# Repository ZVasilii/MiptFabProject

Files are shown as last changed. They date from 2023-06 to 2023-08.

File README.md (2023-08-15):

# Робот-бармен

Идея проекта в создании робота-бармена для использования его на студенческих мероприятиях. 
Проект был создан на "Физтех.Фабрике" в 2023 году.

### Авторы

Студенты 4 Курса ФРКТ:

Зайцев Василий  
Алексей Быков  
Касков Михаил  

## Подробнее

См. презентацию [здесь](https://github.com/ZVasilii/MiptFabProject/blob/master/%D0%A0%D0%BE%D0%B1%D0%BE%D1%82-%D0%B1%D0%B0%D1%80%D0%BC%D0%B5%D0%BD.pptx)

### Собранное устройство



## Используемые компоненты

* Arduino Nano
* Энкодер с кнопкой
* Аквариумный насос
* Пищевой силиконовый шланг
* Шаговый двигатель 28BYJ-48 5V
* Сервопривод FS5103B
* Тензодатчик (датчик веса)
* Экран Lcd 1602 I2C

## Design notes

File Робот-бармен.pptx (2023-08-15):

## Робот-бармен

Выполнили студенты ФРКТ
Зайцев Василий Б01-909
Быков Алексей Б01-908
Касков Михаил Б01-909

## Цель

- Избавить студентов от необходимости замешивать напитки самостоятельно
- Обеспечить честность и непредвзятость при наливании
- Разработать недорогое, практичное и масштабируемое решение

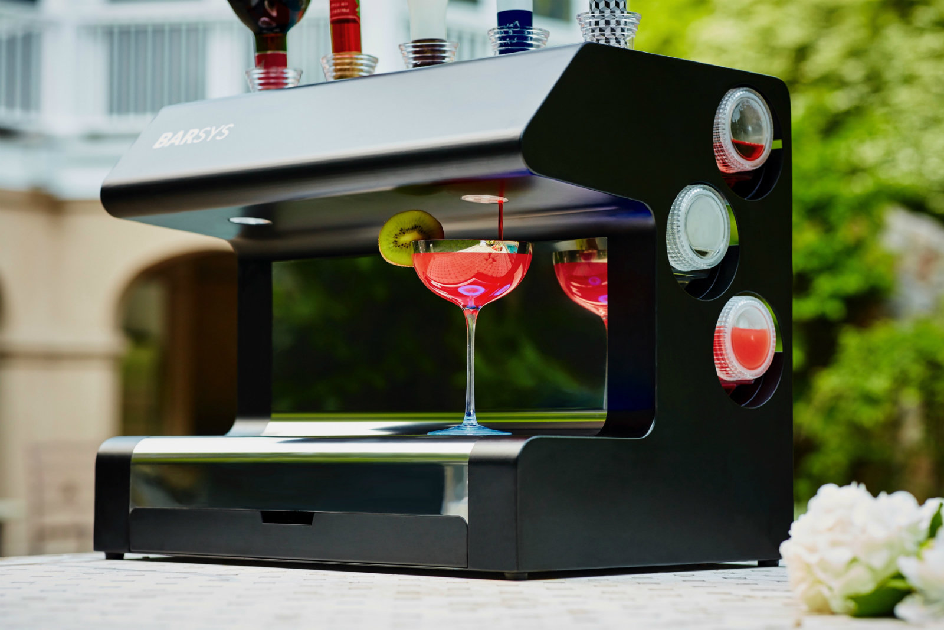
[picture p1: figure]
Робот-бармен» Barsys стоимостью 1500 долларов наделен искусственным интеллектом

## Схема Работы

Выбор напитка через энкодер, индикация на LCD

Выбор нужной емкости, включение насоса

Контроль веса тензодатчиком, остановка насоса

Окончание приготовления, индикация светодиодом

## Первый прототип клапана выбора

- Основан на циллиндре с отверстиями
- Выбор осуществлялся поворотом шагового двигателя
- Недостаток – низкая герметичность не позволяла обеспечить нужное давление

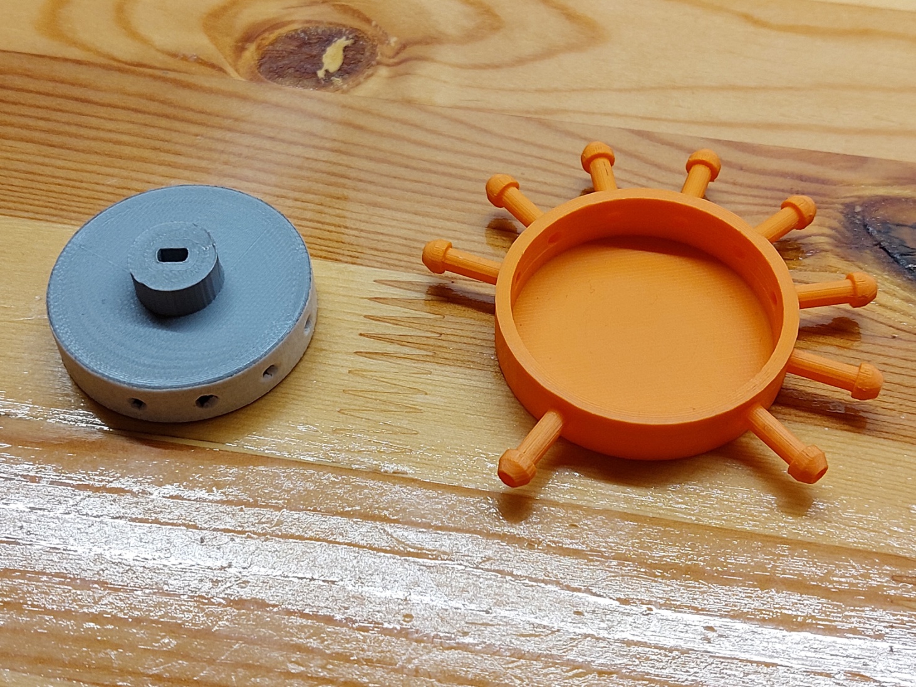
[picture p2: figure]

## Рабочее решение клапана выбора

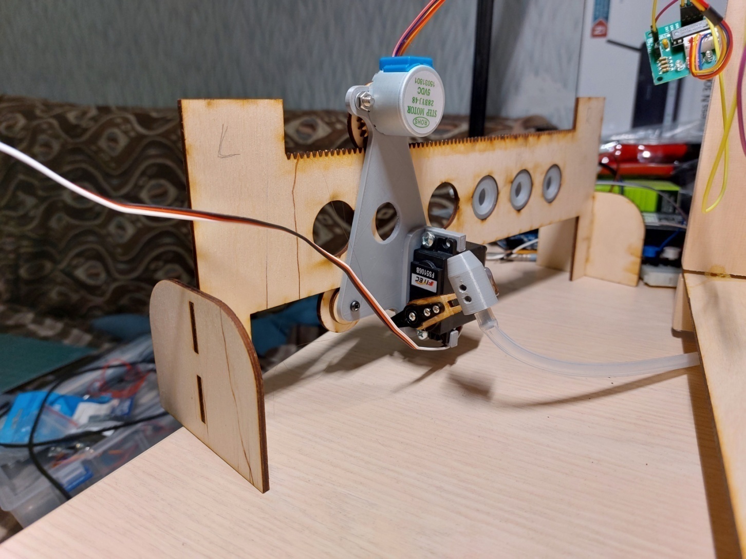
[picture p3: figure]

- Основан на рельсе с отверстиями
- Выбор происходит шаговым двигателем
- «Стыковка» и герметизация - серводвигателем

## API для добавления рецептов

- changeValve – сменить емкость
- pumpON/OFF – вкл/выкл насос
- waitForGramms – к-во грамм, сколько нужно налить

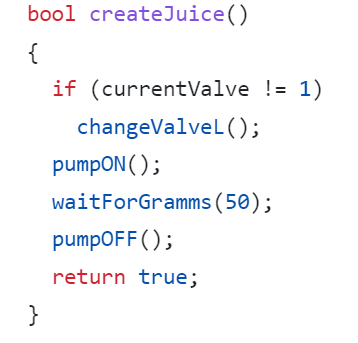
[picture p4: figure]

## Достоинства и недостатки нашего решения

- Достоинства:
  - Простота и дешевизна конструкции (около 1000р)
  - Открытый исходный код и доступные материалы
  - Система построена так, что «живительный напиток» проходит только через трубки из пищевого силикона и не соприкасается с клапанами/насосами
  - Масштабируемость, удобный API для введения новых рецептов
  - Удобный user interface, индикация работы
  - Недостатки
    - Стабильность работы клапана выбора

## Использованные компоненты/материалы

- Фанера
- Серводвигатель FS5103B
- Шаговый двигатель 28BYJ-48 5V
- Энкодер
- LCD дисплей 1602
- Тензодатчик
- Аквариумная помпа
- Трубки из пищевого силикона
- Реле
- Провода/Резисторы/Диоды
- Arduino Nano

## Возможные улучшения

- Редактирование рецептов на самом аппарате
- Улучшение стабильности клапана выбора
- Подсветка рабочей зоны в цвет напитка
- Проверка на опустошение исходных емкостей
- Проверка на перелив стакана
- Добавить перемешивание напитков

## Демонстрация работы

## Процесс разработки

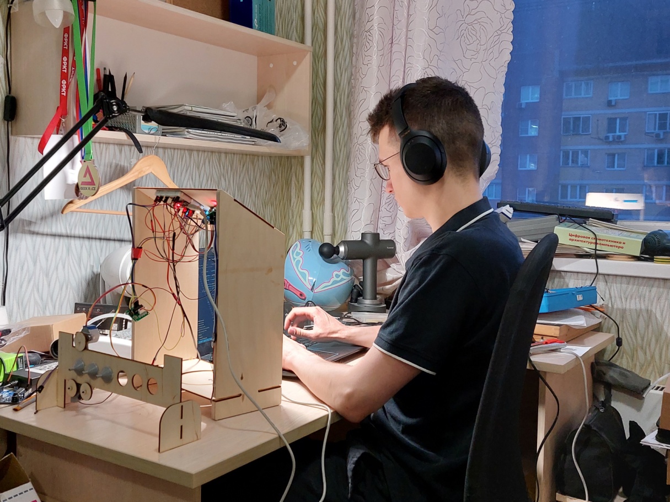
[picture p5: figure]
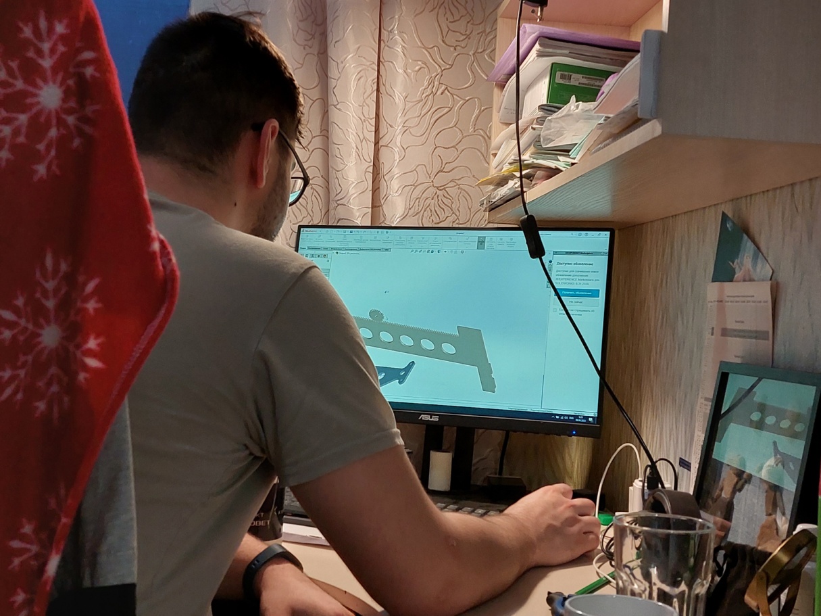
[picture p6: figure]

## Спасибо за Внимание

Github: https://github.com/ZVasilii/MiptFabProject

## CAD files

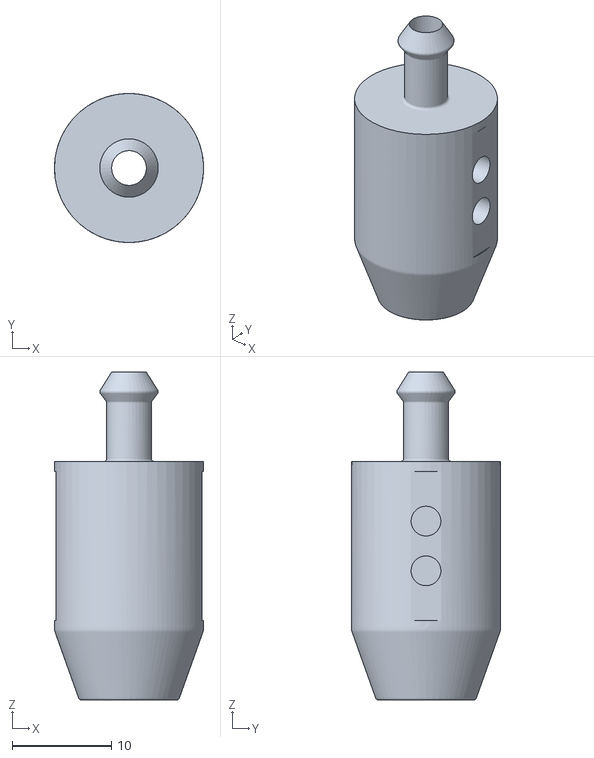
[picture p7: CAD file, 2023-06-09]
src/barMachine/CAD/pipe.STL
15.0 x 15.0 x 33.0

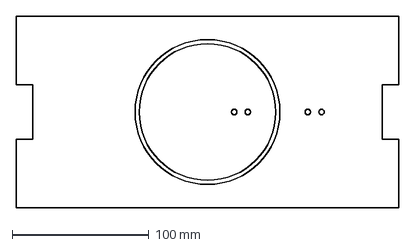
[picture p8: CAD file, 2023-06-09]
src/barMachine/CAD/table.DXF
280.0 x 140.0 mm

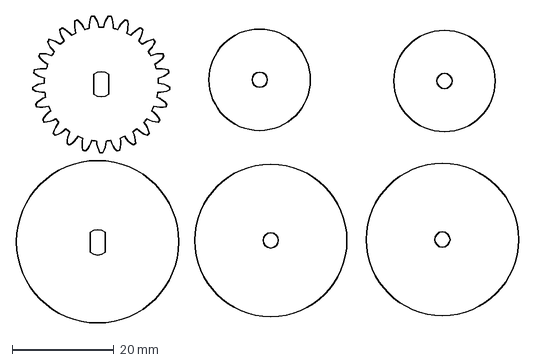
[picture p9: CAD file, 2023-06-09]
src/barMachine/CAD/gear.dxf
98.9 x 60.5 mm

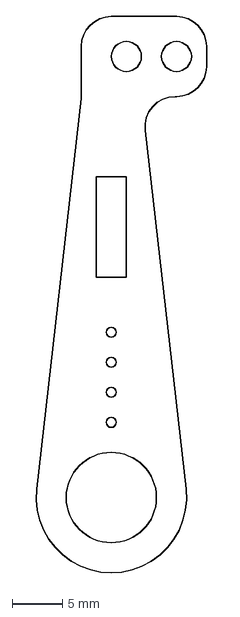
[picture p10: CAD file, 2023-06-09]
src/barMachine/CAD/pipe_holder.DXF
17.3 x 55.9 mm

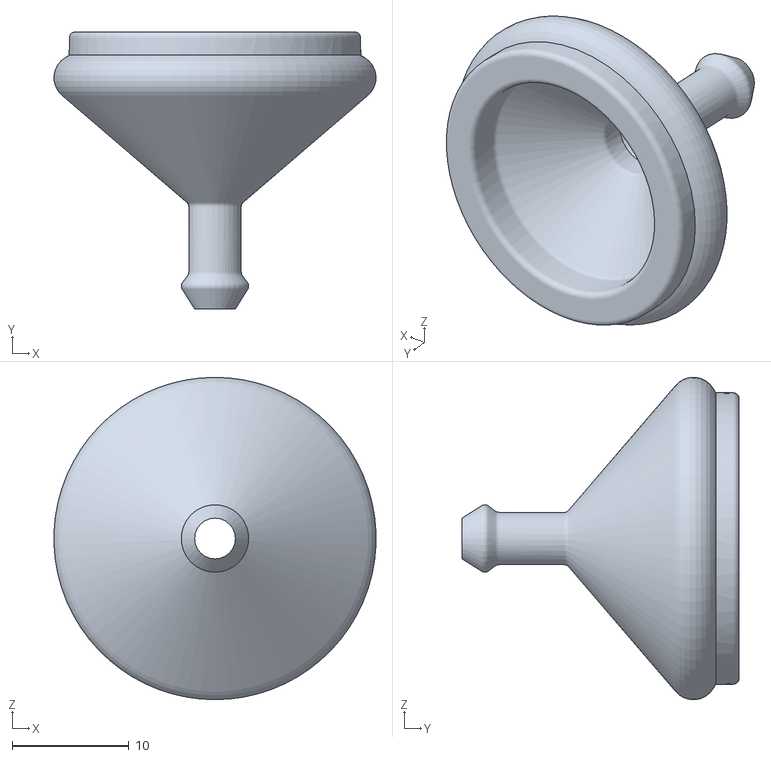
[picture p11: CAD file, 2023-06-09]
src/barMachine/CAD/output.STL
27.6 x 23.8 x 27.6

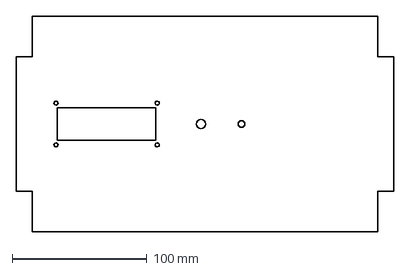
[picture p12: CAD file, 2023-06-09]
src/barMachine/CAD/control_panel.DXF
280.0 x 160.0 mm

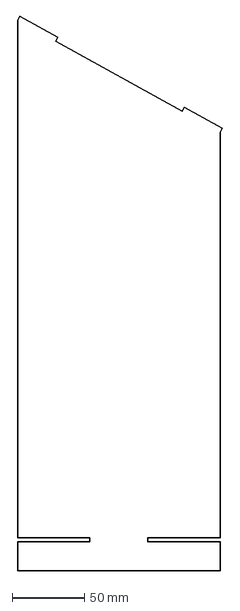
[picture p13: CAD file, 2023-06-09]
src/barMachine/CAD/wall.DXF
141.5 x 383.1 mm

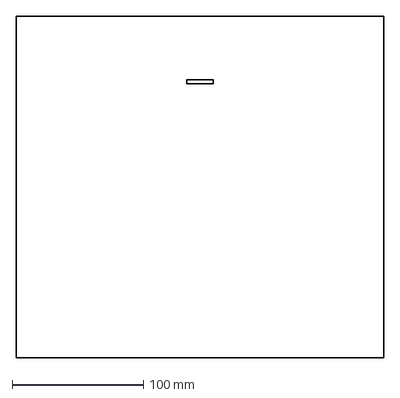
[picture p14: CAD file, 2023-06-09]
src/barMachine/CAD/back_wall.DXF
280.0 x 260.0 mm

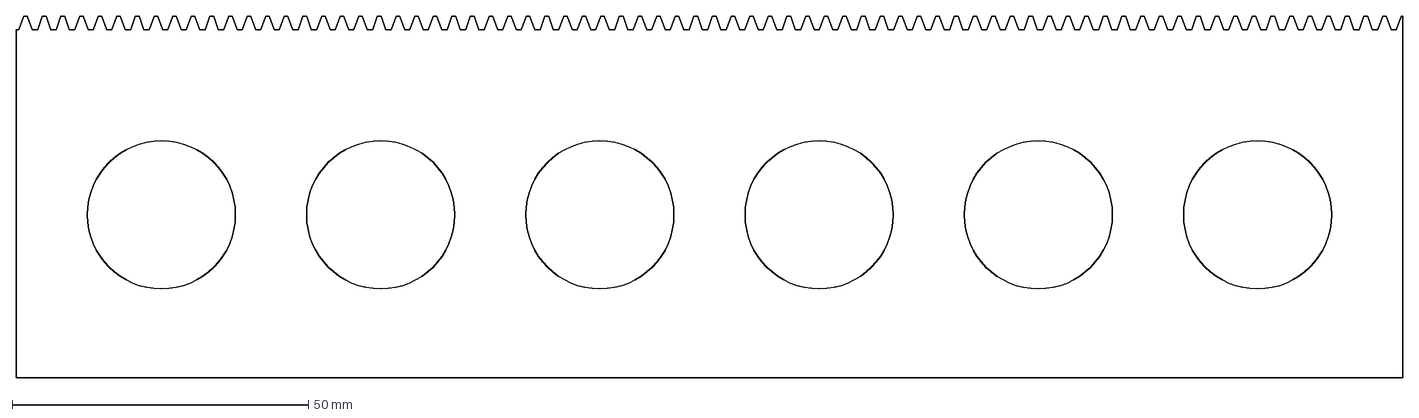
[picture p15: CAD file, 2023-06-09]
src/barMachine/CAD/rail.DXF
234.0 x 61.0 mm

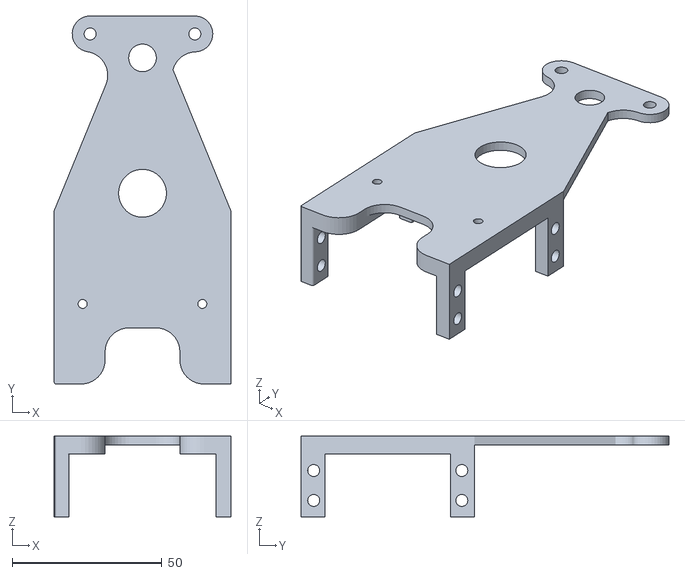
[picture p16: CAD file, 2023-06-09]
src/barMachine/CAD/holder.STL
59.0 x 123.0 x 27.0

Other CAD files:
src/barMachine/CAD/output.DXF

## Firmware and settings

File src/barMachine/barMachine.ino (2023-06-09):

#include "recipies.h"

enum State {VODKA, JUICE, SCREW};
String strState[NUM_STATES] = {"VODKA",  "JUICE ", "SCREW "};
enum PUMP_STATE {ON, OFF};


int currentState = 0;
int pumpState = OFF;

const uint32_t millisThreshold = 500;
uint32_t lastMillis = 0;

long weightRaw = 0;
long weight = 0;

void setup() {
  pinMode(PIN_RELAY, OUTPUT);
  pinMode(PIN_DIODE, OUTPUT);
  stp.setSpeed(10);
  Serial.begin(9600);
  srv.attach(PIN_SERVO);
  srv.write(SERVO_DEFAULT);

  calibrateWeight();
  lcd.init();
  lcd.backlight();// Включаем подсветку дисплея
  lcd.print("BAR MACHINE RELEASE");
  delay(500);
  lcd.clear();
  lcd.print("Calibrated");
  delay(500);
  lcd.clear();
}

void loop() {
  enc.tick();

  if (enc.turn()) {
    currentState = changeState(enc.dir(), currentState);
    #ifdef DEBUG
      Serial.println(currentState);
    #endif
  }

  if (millis() - lastMillis > millisThreshold)
  {
    weightRaw = getWeightValue();
    //CHANGE TO CALIBRATE
    weight = weightRaw/WEIGHT_FACTOR;
    #ifdef DEBUG
      Serial.println( weightRaw);
      Serial.println(weight);
    #endif
    bool btnClicked = enc.click();
    if (btnClicked)
    {
      switch (currentState)
      {
        case State::VODKA:
          createVodka();
          break;
        case State::JUICE:
          createJuice();
          break;
        case State::SCREW:
          createScrewdriver();
          break;
      }
    }
    updateLCD(btnClicked, strState[currentState], weight);
    lastMillis = millis();
  }
}

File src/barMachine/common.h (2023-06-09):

#ifndef _COMMON_HEADER_H
#define _COMMON_HEADER_H

#include <Stepper.h>
#include <LiquidCrystal_I2C.h>
#include <EncButton2.h>
#include <GyverHX711.h>
#include <Servo.h>


//const char PIN_STP[4] = {8, 10, 9, 11};
//const char PIN_BTTN = 2;
const char PIN_WEIGHT_DATA = 6;
const char PIN_WEIGHT_SCK = 5;
const int PIN_RELAY = 12;
const int PIN_SERVO = 7;
const int PIN_DIODE = 13;
const char PIN_STP[4] = {8, 10, 9, 11};
const char PIN_ENC[3] = {2, 3, 4};
const int TMP_DELAY = 4000;
const int NUM_STATES = 3;
const int SERVICE_DELAY = 200;
const int FULL_REVOLUTION = 2048;
const int ONE_STEP = 980;
const int SERVO_DEFAULT = 0;
const int SERVO_ATTACHED = 75;
const int WEIGHT_FACTOR = 375;
#endif

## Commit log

2023-04-21 Add functions to operate stepper motor and relay
2023-04-28 Add encoder support, LCD display
2023-04-28 Add YAML with pin scheme
2023-05-12 Add weight sensor interface
2023-05-26 1st version of liquid pump
2023-06-08 edit LCD number view error, change calibration function for weight
    [barMachine.ino]
2023-06-08 Add stepper motor bug
    [common.h]
2023-06-08 Prototype 2
2023-06-09 Working prototype
2023-06-09 add CAD files
    [back_wall.DXF, control_panel.DXF, gear.dxf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]
